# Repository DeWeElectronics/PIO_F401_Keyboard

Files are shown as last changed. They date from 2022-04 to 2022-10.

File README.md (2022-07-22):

# STM32 Mechanical Keyboard

a DIY attempt of a 68 key style mechanical keyboard which not only looks cool, but can also scan at 1000 Hz

click the image below to watch the build video on youtube.

Youtube Video of the build process (http://www.youtube.com/watch?v=smThnvXJ02c)

This keyboard is powered with a STM32F401CC board (a.k.a black pill F401CC)



To build this project, simply clone this project and build it in vscode with PlatformIO IDE

Note : Before building and flashing to the microcontroller, make sure that the keyboard wiring matches this schematic



or instead change the matrix pin definitions in src/main.c (rowPins and colPins) to fit your wiring while paying attention to the key mapping in src/keymap.c

"secret" features:
  - AutoType mode: The keyboard will turn into an automatic text typer configured to output a specific text defined in src/text.c. Each key press will send a character of the text, and a long press will send the characters continuously. Enable autotype mode by pressing and holding FN and all five right-most keys.  
  - AutoPress mode: The keyboard will repeatedly press and unpress the enabled key(s). Enable autopress mode by defining ENABLE_AUTOTYPER in src/main.c (definition has been commented out). Flash the new firmware. Then, on the keyboard, press FN, and the key desired (a key without an alternate mode to avoid conflict with alternate key). Then a long press will repeatedly send the desired key. Disable it by again pressing FN and the desired key, or to disable it for the entire keyboard, press FN and ESC

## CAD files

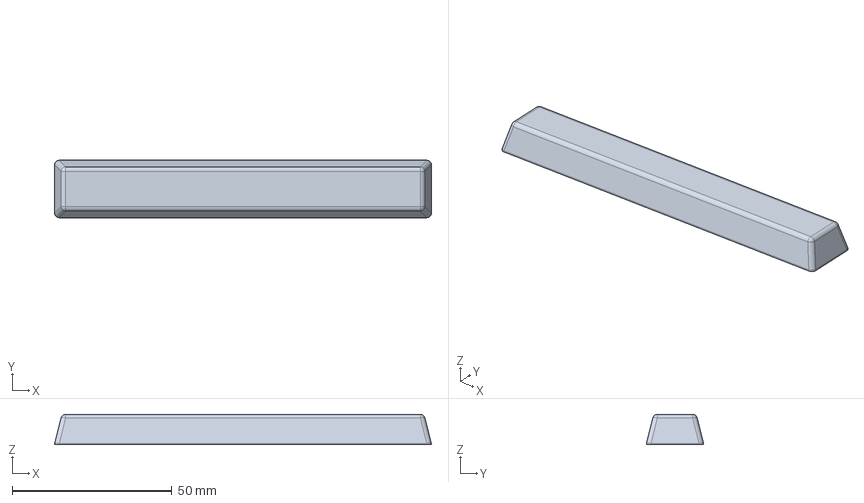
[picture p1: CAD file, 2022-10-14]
STL_Files/FreeCAD files/keycaps uniform 6_25u.FCStd
118.0 x 18.0 x 9.50 mm

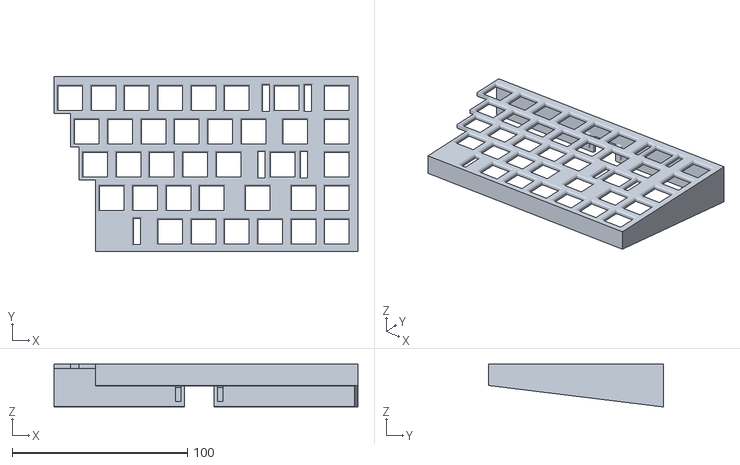
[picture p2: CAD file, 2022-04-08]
STL_Files/KTR_1.stl
173.2 x 100.0 x 24.5

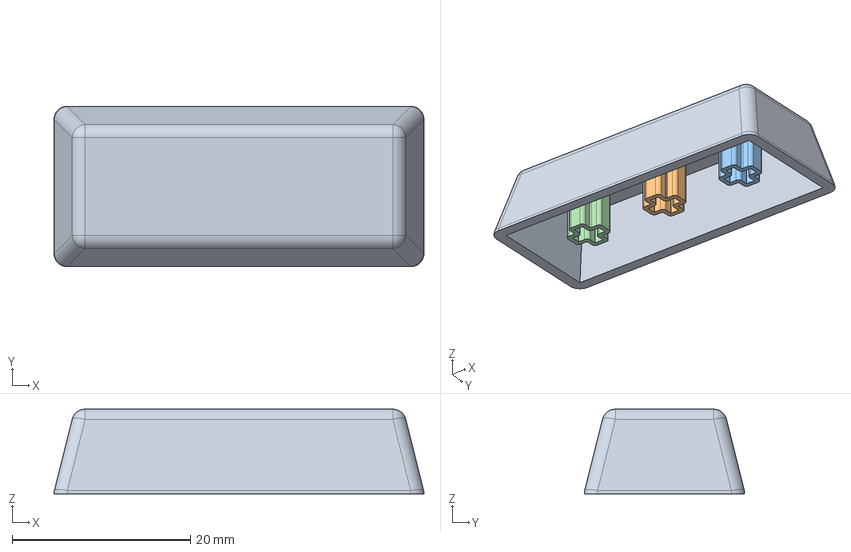
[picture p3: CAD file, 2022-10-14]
STL_Files/FreeCAD files/keycaps uniform 2.25u.FCStd
41.5 x 18.0 x 9.50 mm

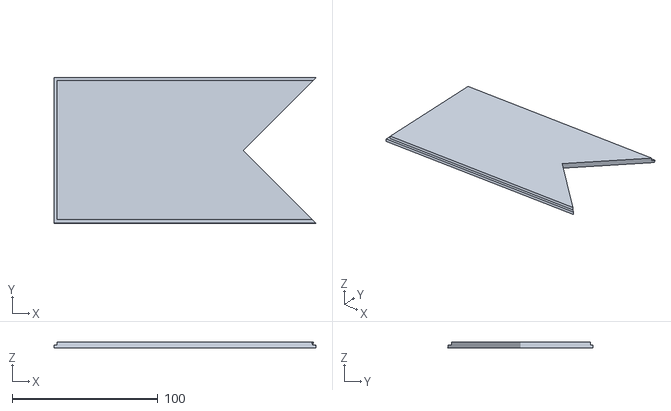
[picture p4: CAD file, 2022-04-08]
STL_Files/KBL_1.stl
180.0 x 100.0 x 4.00

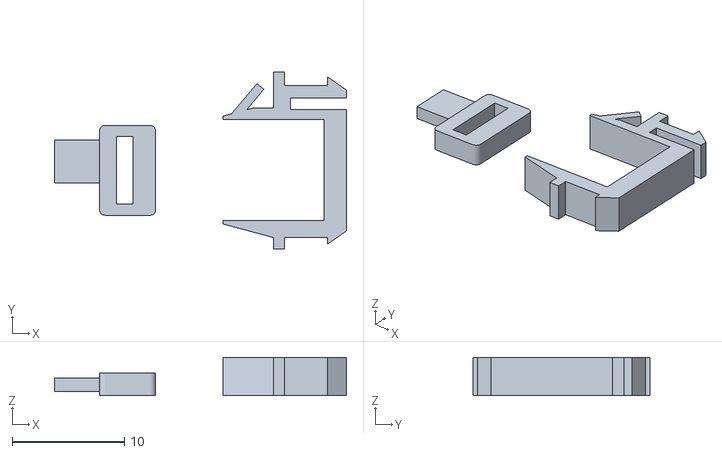
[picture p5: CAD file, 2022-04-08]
STL_Files/costar-stab.stl
26.0 x 15.7 x 3.40

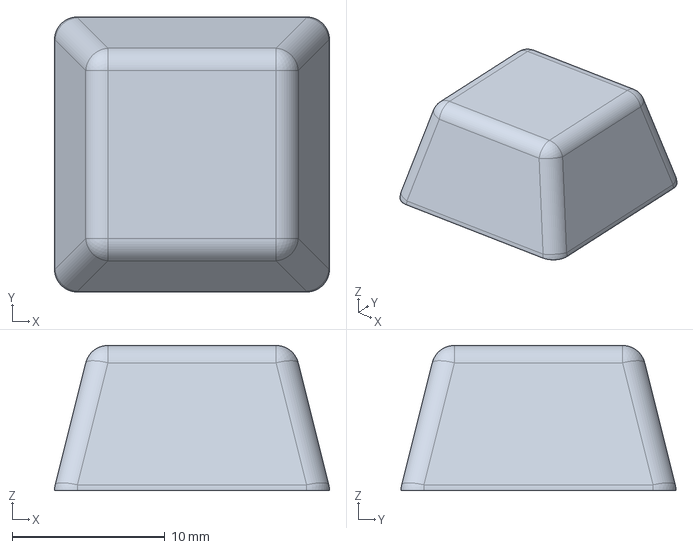
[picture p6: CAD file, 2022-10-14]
STL_Files/FreeCAD files/keycaps uniform.FCStd
18.0 x 18.0 x 9.50 mm

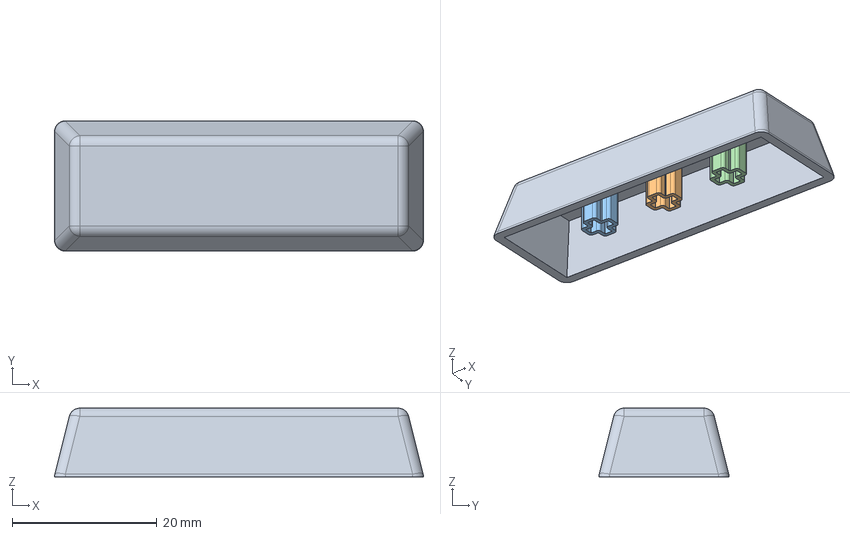
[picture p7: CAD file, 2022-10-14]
STL_Files/FreeCAD files/keycaps uniform 2.75u.FCStd
51.0 x 18.0 x 9.50 mm

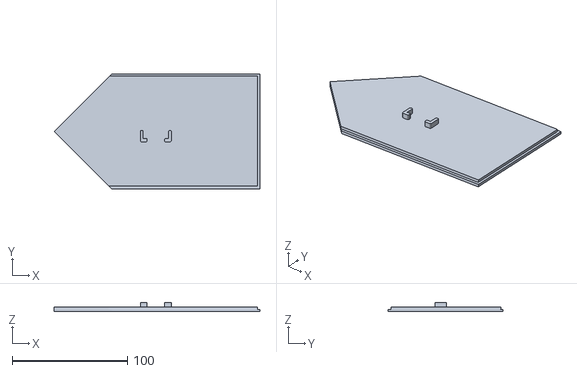
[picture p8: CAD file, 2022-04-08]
STL_Files/KBR_1.stl
179.0 x 100.0 x 8.00

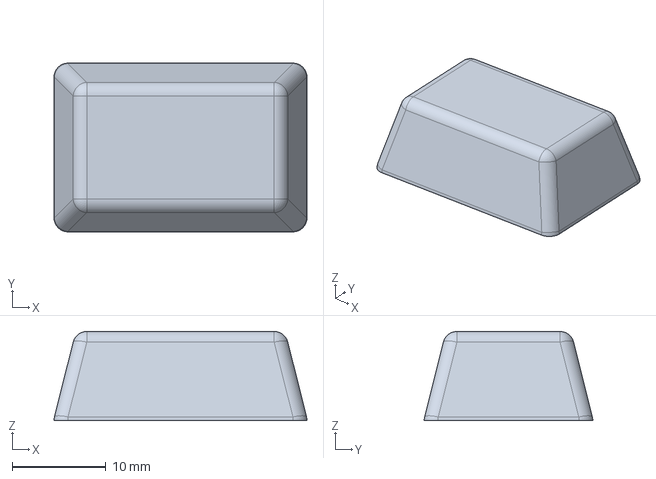
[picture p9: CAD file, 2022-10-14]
STL_Files/FreeCAD files/keycaps uniform 1_5u.FCStd
27.0 x 18.0 x 9.50 mm

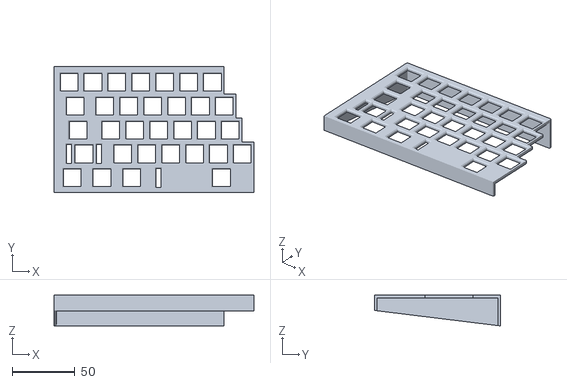
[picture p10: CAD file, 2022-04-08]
STL_Files/KTL_1.stl
159.0 x 100.0 x 24.5

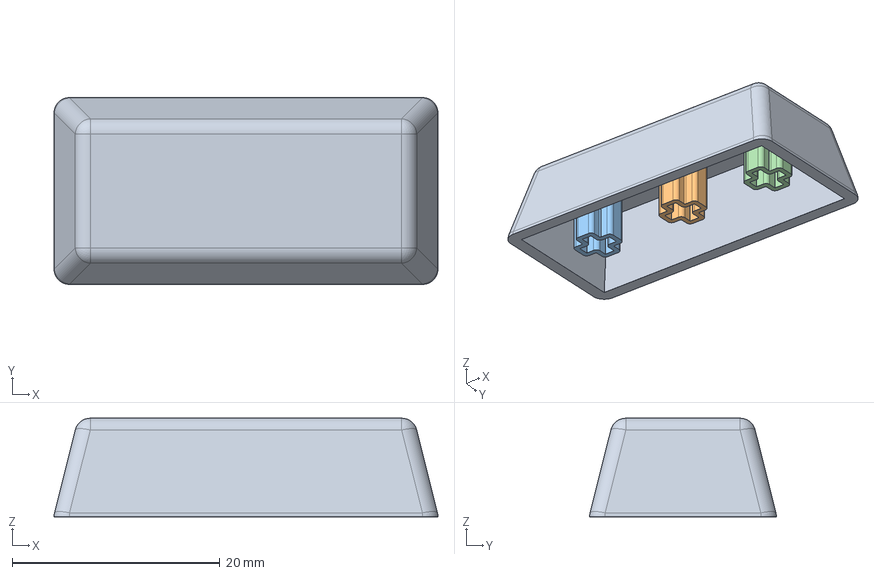
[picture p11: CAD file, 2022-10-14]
STL_Files/FreeCAD files/keycaps uniform 2u.FCStd
37.0 x 18.0 x 9.50 mm

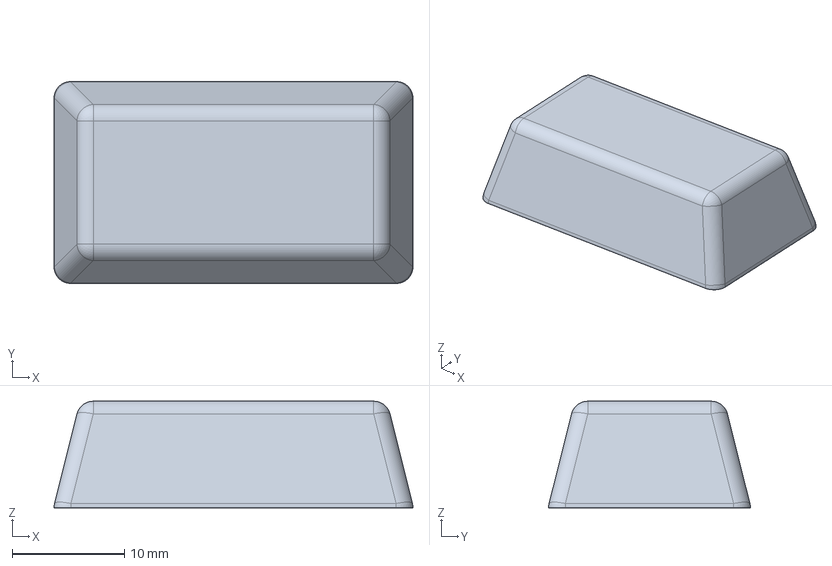
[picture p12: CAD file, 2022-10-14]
STL_Files/FreeCAD files/keycaps uniform 1_75u.FCStd
32.0 x 18.0 x 9.50 mm

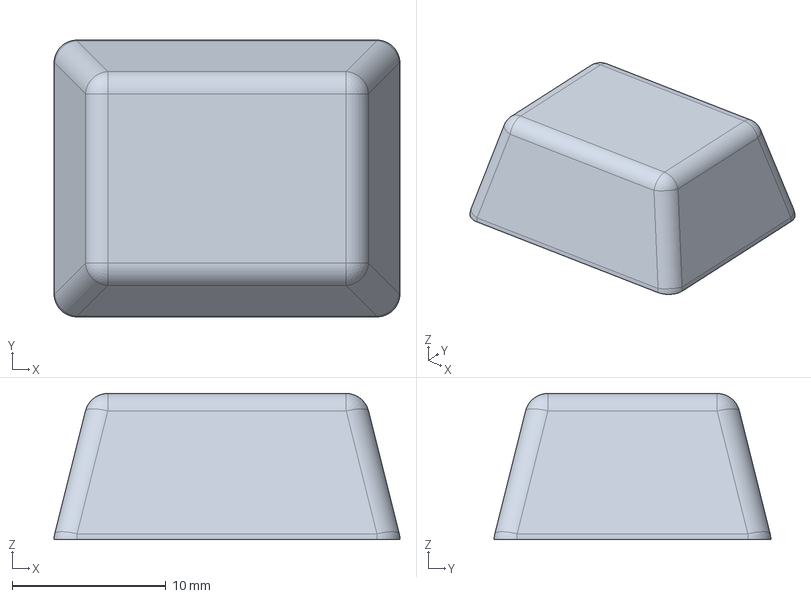
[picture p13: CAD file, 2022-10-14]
STL_Files/FreeCAD files/keycaps uniform 1_25u.FCStd
22.5 x 18.0 x 9.50 mm

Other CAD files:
STL_Files/FreeCAD files/costar_stabs.FCStd
STL_Files/FreeCAD files/keyboard_frame.FCStd
STL_Files/keycaps uniform 1_25u.stl
STL_Files/keycaps uniform 1_5u.stl
STL_Files/keycaps uniform 1_75u.stl
STL_Files/keycaps uniform 2.25u.stl
STL_Files/keycaps uniform 2.75u.stl
STL_Files/keycaps uniform 2u.stl
STL_Files/keycaps uniform 6_25u.stl
STL_Files/keycaps uniform.stl

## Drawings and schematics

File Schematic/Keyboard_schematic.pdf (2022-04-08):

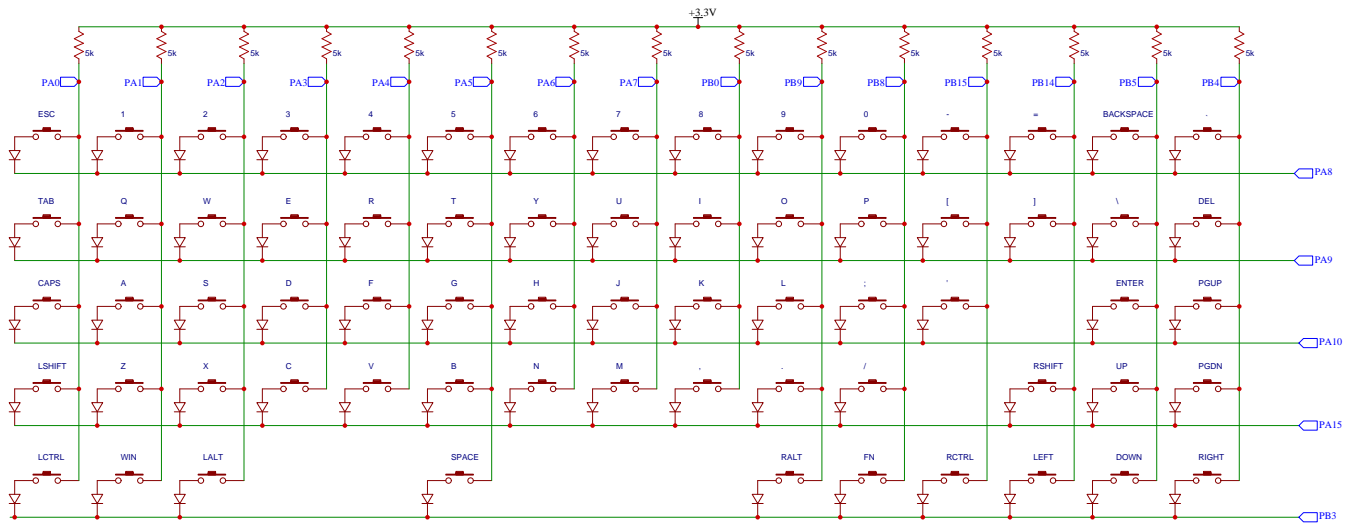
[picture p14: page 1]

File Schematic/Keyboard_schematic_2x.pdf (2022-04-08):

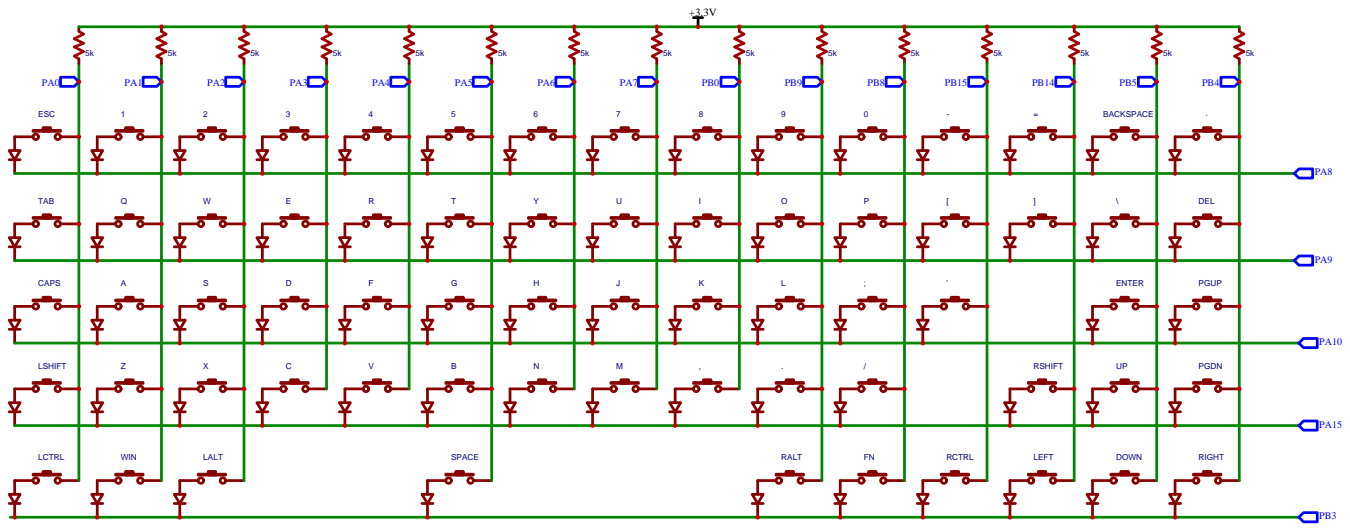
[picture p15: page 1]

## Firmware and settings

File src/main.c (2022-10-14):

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
/* Includes ------------------------------------------------------------------*/
#include "main.h"
#include "usb_device.h"

/* USER CODE BEGIN Includes */
#include "GPIO_Config.h"
#include "keyboard_usb.h"
#include "keymap.h"
#include "stdlib.h"
#include "string.h"
#include "text.h"
/* USER CODE END Includes */

TIM_HandleTypeDef htim3;

void SystemClock_Config(void);
static void MX_GPIO_Init(void);
static void MX_TIM3_Init(void);
/* USER CODE BEGIN 0 */

#define TIMEOUT_MS 100
#define TIMEOUT_MAX 500

extern USBD_HandleTypeDef hUsbDeviceFS;

// #define ENABLE_AUTOTYPER

#define USBD_Keyboard_State() (((volatile USBD_HID_HandleTypeDef*)hUsbDeviceFS.pClassData)->state)

#define COLS 15U
#define ROWS 5U

PinId_t* colPins[COLS] = {
    PA0, PA1, PA2, PA3, PA4,
    PA5, PA6, PA7, PB0, PB9,
    PB8, PB15, PB14, PB5, PB4};

PinId_t* rowPins[ROWS] = {
    PA8,
    PA9,
    PA10,
    PA15,
    PB3,
};

#define HID_NORMAL_ID 1U
#define HID_MEDIA_ID 2U
#define FN_KEY 70U

void keyboard_init(PinId_t** p_rows, PinId_t** p_cols, uint16_t n_rows, uint16_t n_cols) {
    
    __HAL_RCC_GPIOA_CLK_ENABLE();
    __HAL_RCC_GPIOB_CLK_ENABLE();
    __HAL_RCC_GPIOC_CLK_ENABLE();

    for (uint16_t i = 0; i < n_cols; i++) {
        GPIO_InitTypeDef tmp = {0};
        tmp.Pin = p_cols[i]->pinmask;
        tmp.Mode = GPIO_MODE_INPUT;
        tmp.Pull = GPIO_PULLUP;
        tmp.Alternate = 0U;
        HAL_GPIO_Init(p_cols[i]->GPIOx, &tmp);
    }

    for (uint16_t i = 0; i < n_rows; i++) {
        PinId_Write(p_rows[i], 1);
        GPIO_InitTypeDef tmp = {0};
        tmp.Pin = p_rows[i]->pinmask;
        tmp.Mode = GPIO_MODE_OUTPUT_PP;
        tmp.Pull = GPIO_NOPULL;
        tmp.Speed = GPIO_SPEED_FREQ_VERY_HIGH;
        tmp.Alternate = 0U;
        HAL_GPIO_Init(p_rows[i]->GPIOx, &tmp);
    }
}

void keyboard_transmit(uint8_t* data, size_t size) {
    while (USBD_Keyboard_State() != HID_IDLE)
        ;
    USBD_HID_SendReport(&hUsbDeviceFS, data, size);
}

KeyboardHID_t myHID = {HID_NORMAL_ID};
MediaHID_t myMedia = {HID_MEDIA_ID};
uint8_t Pressed[ROWS * COLS] = {0};
uint32_t keyTimer[ROWS * COLS] = {0};
#define ENABLE_AUTOTYPER
#ifdef ENABLE_AUTOTYPER
uint8_t autoPress[ROWS * COLS] = {0};
#endif //ENABLE_AUTOTYPER

void keyboardService() {
    static uint32_t update = 0;
    static uint32_t alternate = 0;
    static uint32_t autotype = 0;
    static uint32_t clean = 0;
    static uint8_t autotypeActivate = 0;
    static uint32_t textPos = 0;
    static uint32_t npressed = 0;

    // scan matrix
    for (uint32_t i = 0; i < ROWS; i++) {
        PinId_Write(rowPins[i], 0);
        volatile uint32_t j = 0;
        for (; j < 10; j++)
            ;
        for (j = 0; j < COLS; j++) {
            uint32_t pos = i * COLS + j;
            uint32_t col_pressed = !PinId_Read(colPins[j]);
            uint32_t thisTick = HAL_GetTick();

            // set/unset alternate mode
            if (pos == FN_KEY) {
                alternate = col_pressed;
                continue;
            }

            if (col_pressed) {
                // autotype mode toggle on press (press and release alt key and column 14 of each row simultaneously)
                if (j == 14) {
                    autotypeActivate |= (1U << i);
                    if ((autotypeActivate == 0x1f) && (alternate == 1)) {
                        if (autotype == 0U) autotype = 2U;
                        else if (autotype == 3U) autotype = 1U;
                    }
                }

                // if alternate mode is on and alternate key is defined
                uint8_t key = (alternate && keys_alternate[pos][0] != 0) ? 
                                (uint8_t)keys_alternate[pos][0] : (uint8_t)keys[pos][0];

#ifdef ENABLE_AUTOTYPER
                if(keys_alternate[pos][0] == 0 && alternate) {
                    switch(autoPress[pos]) {
                        case 0: autoPress[pos] = 2; break;
                        case 3: autoPress[pos] = 1; break;
                        default: break;
                    }
                }
#endif // ENABLE_AUTOTYPER

                // press key
                // if key of 'pos' is free and not in debounce timeout
                // if (Pressed[pos] == 0 && TimeOut[pos] == 0) {
                if (Pressed[pos] == 0 && (thisTick - keyTimer[pos] >= TIMEOUT_MS)) {
                    uint32_t keycode = 0UL;
                    if ((keycode = USBD_Keyboard_str_press(&myHID, &myMedia, key))) {
                        update |= ((keycode & KEY_TYPE_MASK) == KEY_TYPE_MEDIA) ? 8U : 4U; // update HID Type
                        update |= 1U;                                                  // update pressed flag
                        Pressed[pos] = key;                                            // assign key to pressed array
                        npressed++;
                    }
                }
#ifdef ENABLE_AUTOTYPER
                if ((autoPress[pos] == 3) && (Pressed[pos] != 0) && (thisTick - keyTimer[pos] >= TIMEOUT_MAX)) {
                    uint32_t keycode = 0UL;
                    if ((keycode = USBD_Keyboard_str_release(&myHID, &myMedia, Pressed[pos]))) {
                        // update HID Type
                        update |= ((keycode & KEY_TYPE_MASK) == KEY_TYPE_MEDIA) ? 8U : 4U;
                        update |= 2U;              // update release flag
                        Pressed[pos] = 0;          // unassign key from pressed array
                        // TimeOut[pos] = TIMEOUT_MS; // set debounce timeout
                        npressed--;
                    }
                    keyTimer[pos] = thisTick - TIMEOUT_MAX + 50;
                }
#endif // ENABLE_AUTOTYPER
            } 
            if(!col_pressed) {
                // autotype mode toggle on release (press and release alt key and column 14 of each row simultaneously)
                if (j == 14) {
                    autotypeActivate &= ~(1U << i);
                    if (autotypeActivate == 0) {
                        int prevautotype = autotype;
                        if (autotype == 2U) autotype = 3U;
                        else if (autotype == 1U) autotype = 0U;
                        if (prevautotype != autotype) 
                            { clean = 1; textPos = 0; }
                    }
                }

#ifdef ENABLE_AUTOTYPER
                switch(autoPress[pos]) {
                    case 2: autoPress[pos] = 3; break;
                    case 1: autoPress[pos] = 0; break;
                    default: break;
                }
#endif // ENABLE_AUTOTYPER
                
                // release key
                if (Pressed[pos] != 0) { // if key[pos] is pressed
                    uint32_t keycode = 0UL;
                    if ((keycode = USBD_Keyboard_str_release(&myHID, &myMedia, Pressed[pos]))) {
                        // update HID Type
                        update |= ((keycode & KEY_TYPE_MASK) == KEY_TYPE_MEDIA) ? 8U : 4U;
                        update |= 2U;              // update release flag
                        Pressed[pos] = 0;          // unassign key from pressed array
                        npressed--;
                    }
                    keyTimer[pos] = thisTick;
                }
                // keep the max difference of keyTimer and thisTick at TIMEOUT_MS (to avoid overflow)
                keyTimer[pos] = (thisTick - keyTimer[pos] > TIMEOUT_MS)? 
                                    (thisTick - TIMEOUT_MS) : keyTimer[pos];
            }
            keyTimer[pos] = (thisTick - keyTimer[pos] > TIMEOUT_MAX)? 
                                (thisTick - TIMEOUT_MAX) : keyTimer[pos];
        }
        PinId_Write(rowPins[i], 1);
    }

#ifdef ENABLE_AUTOTYPER
    if (autoPress[0] == 3)
        clean = 1;
#endif // ENABLE_AUTOTYPER
    
    static uint32_t autotypeTimer = 0;
    if (autotype == 3) {    // autotype long press
        if ((HAL_GetTick() - autotypeTimer >= 500) && npressed > 0) {
            update |= 1U;
            autotypeTimer = HAL_GetTick() - (500);
        } else if (npressed == 0) {
            autotypeTimer = HAL_GetTick();
            textPos %= size_txt;
        }
    }

    // send report
    if (update & 3U) {
        if (clean) { // clean output
#ifdef ENABLE_AUTOTYPER
            memset(autoPress, 0, sizeof(autoPress));
#endif // ENABLE_AUTOTYPER
            uint8_t tmp[9] = {HID_NORMAL_ID, 0, 0, 0, 0, 0, 0, 0, 0};
            uint8_t tmp1[3] = {HID_MEDIA_ID, 0, 0};
            keyboard_transmit((uint8_t*)tmp, 9);
            keyboard_transmit((uint8_t*)tmp1, 3);
            clean = 0;
        }
        if (((update & 1U) == 1U) && autotype == 3) { // autotype mode
            // new HID instance
            KeyboardHID_t autotypeHID = {HID_NORMAL_ID, 0, 0, {0, 0, 0, 0, 0, 0}};
            MediaHID_t autotypeMedia = {HID_MEDIA_ID, {0, 0}};
            // press
            if (textPos < size_txt) {
                uint32_t type = USBD_Keyboard_str_press(&autotypeHID, &autotypeMedia, txt[textPos++]);
                type = (type & KEY_TYPE_MASK) == KEY_TYPE_MEDIA;
                if (type) {
                    keyboard_transmit((uint8_t*)&autotypeMedia, sizeof(autotypeMedia));
                    // release
                    USBD_Keyboard_releaseAll(&autotypeHID, &autotypeMedia);
                    keyboard_transmit((uint8_t*)&autotypeMedia, sizeof(autotypeMedia));
                } else {
                    keyboard_transmit((uint8_t*)&autotypeHID, sizeof(autotypeHID));
                    // release
                    USBD_Keyboard_releaseAll(&autotypeHID, &autotypeMedia);
                    keyboard_transmit((uint8_t*)&autotypeHID, sizeof(autotypeHID));
                }
            }
        } else if (autotype == 0) { // normal mode
            if (update & 8U) {
                myMedia.ID = HID_MEDIA_ID;
                keyboard_transmit((uint8_t*)&myMedia, sizeof(myMedia));
            }
            if (update & 4U) {
                myHID.ID = HID_NORMAL_ID;
                keyboard_transmit((uint8_t*)&myHID, sizeof(myHID));
            }
        }
        update = 0;
    }
}

volatile uint32_t LED_toggle = 0U;

void USBD_HID_GetReport(uint8_t* OutData, int len) {
    if (OutData[0] == 0x01) {
        PinId_Write(PC14, OutData[1] & 1U);
        PinId_Write(PC15, OutData[1] & 2U);
    }
}

void __attribute__((optimize("-O0"))) HAL_TIM_PeriodElapsedCallback(TIM_HandleTypeDef* htim) {

    if (htim == &htim3) {
        PinId_Write(PC13, !(!(USBD_Keyboard_State() == HID_IDLE) || PinId_Read(PC13)));
        // PinId_Write(PC13, !((USBD_Keyboard_State() == HID_IDLE) && PinId_Read(PC13)));
        // if (USBD_Keyboard_State() == HID_IDLE)
        //     PinId_Toggle(PC13);
    }
    // NVIC_DisableIRQ(TIM3_IRQn);
    // keyboardService();
    // NVIC_EnableIRQ(TIM3_IRQn);
}

/* USER CODE END 0 */

/**
 * @brief  The application entry point.
 * @retval int
 */
int __attribute__((optimize("-O0"))) main(void) {
    /* MCU Configuration--------------------------------------------------------*/

    /* Reset of all peripherals, Initializes the Flash interface and the Systick. */
    HAL_Init();

    /* Configure the system clock */
    SystemClock_Config();

    /* USER CODE BEGIN SysInit */

    NVIC_SetPriority(OTG_FS_IRQn, 6);
    NVIC_SetPriority(TIM3_IRQn, 67);
    /* USER CODE END SysInit */

    /* Initialize all configured peripherals */
    MX_GPIO_Init();
    MX_TIM3_Init();
    HAL_Delay(50);
    MX_USB_DEVICE_Init();
    HAL_Delay(50);
    /* USER CODE BEGIN 2 */
    keyboard_init(rowPins, colPins, ROWS, COLS);
    TIM3->PSC = (84000000 / 10000) - 1;
    TIM3->ARR = (10000 / 1) - 1;
    // NVIC_SetPriority(OTG_FS_IRQn, 6);
    // NVIC_SetPriority(TIM3_IRQn, 67);
    HAL_TIM_Base_Start_IT(&htim3);

    while (USBD_Keyboard_State() != HID_IDLE)
        ;
    LED_toggle = 1U;

    /* USER CODE END 2 */

    /* Infinite loop */
    /* USER CODE BEGIN WHILE */
    while (1) {
        /* USER CODE END WHILE */

        /* USER CODE BEGIN 3 */
        static uint32_t lastScan = 0UL;
        if (lastScan != HAL_GetTick()) {
            lastScan = HAL_GetTick();
            keyboardService();
        }
    }
    /* USER CODE END 3 */
}

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


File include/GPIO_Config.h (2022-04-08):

/*!
 * @file GPIO_Config.h
 * @author Demitrias Wilbert 
 * @brief definition to pointer to each pin configuration structure type (PinId_t)
 * @version 0.1
 * @date 2021-07-08
 * 
 * 
*/

#ifndef GPIO_CONFIG_H
#define GPIO_CONFIG_H

#include "main.h"

/*!
 * @struct PinId_t
 * @brief pin configuration structure typedef
 * 
 * @var PinId_t::GPIO_TypeDef 
 *  pointer to the pin GPIO Base
 * @var PinId_t::pinmask
 *  bitmask of the pin
 * @var PinId_t::pin
 *  index of the pin
 * 
*/
typedef struct
{
    GPIO_TypeDef* GPIOx;
    uint16_t pinmask;
    uint16_t pin;
} PinId_t;


/*!
 * @brief 
 * undef the unnecessary GPIOs to save memory
 * e.g: STM32F103C8T6 only has GPIOA, GPIOB, GPIOC, GPIOD
 * so undef the rest
 *
*/


#ifdef GPIOA
extern const PinId_t PIN_PA0;
#define PA0 ((PinId_t*) &PIN_PA0)
extern const PinId_t PIN_PA1;
#define PA1 ((PinId_t*) &PIN_PA1)
extern const PinId_t PIN_PA2;
#define PA2 ((PinId_t*) &PIN_PA2)
extern const PinId_t PIN_PA3;
#define PA3 ((PinId_t*) &PIN_PA3)
extern const PinId_t PIN_PA4;
#define PA4 ((PinId_t*) &PIN_PA4)
extern const PinId_t PIN_PA5;
#define PA5 ((PinId_t*) &PIN_PA5)
extern const PinId_t PIN_PA6;
#define PA6 ((PinId_t*) &PIN_PA6)
extern const PinId_t PIN_PA7;
#define PA7 ((PinId_t*) &PIN_PA7)
extern const PinId_t PIN_PA8;
#define PA8 ((PinId_t*) &PIN_PA8)
extern const PinId_t PIN_PA9;
#define PA9 ((PinId_t*) &PIN_PA9)
extern const PinId_t PIN_PA10;
#define PA10 ((PinId_t*) &PIN_PA10)
extern const PinId_t PIN_PA11;
#define PA11 ((PinId_t*) &PIN_PA11)
extern const PinId_t PIN_PA12;
#define PA12 ((PinId_t*) &PIN_PA12)
extern const PinId_t PIN_PA13;
#define PA13 ((PinId_t*) &PIN_PA13)
extern const PinId_t PIN_PA14;
#define PA14 ((PinId_t*) &PIN_PA14)
extern const PinId_t PIN_PA15;
#define PA15 ((PinId_t*) &PIN_PA15)
#endif // GPIOA

#ifdef GPIOB
extern const PinId_t PIN_PB0;
#define PB0 ((PinId_t*) &PIN_PB0)
extern const PinId_t PIN_PB1;
#define PB1 ((PinId_t*) &PIN_PB1)
extern const PinId_t PIN_PB2;
#define PB2 ((PinId_t*) &PIN_PB2)
extern const PinId_t PIN_PB3;
#define PB3 ((PinId_t*) &PIN_PB3)
extern const PinId_t PIN_PB4;
#define PB4 ((PinId_t*) &PIN_PB4)
extern const PinId_t PIN_PB5;
#define PB5 ((PinId_t*) &PIN_PB5)
extern const PinId_t PIN_PB6;
#define PB6 ((PinId_t*) &PIN_PB6)
extern const PinId_t PIN_PB7;
#define PB7 ((PinId_t*) &PIN_PB7)
extern const PinId_t PIN_PB8;
#define PB8 ((PinId_t*) &PIN_PB8)
extern const PinId_t PIN_PB9;
#define PB9 ((PinId_t*) &PIN_PB9)
extern const PinId_t PIN_PB10;
#define PB10 ((PinId_t*) &PIN_PB10)
extern const PinId_t PIN_PB11;
#define PB11 ((PinId_t*) &PIN_PB11)
extern const PinId_t PIN_PB12;
#define PB12 ((PinId_t*) &PIN_PB12)
extern const PinId_t PIN_PB13;
#define PB13 ((PinId_t*) &PIN_PB13)
extern const PinId_t PIN_PB14;
#define PB14 ((PinId_t*) &PIN_PB14)
extern const PinId_t PIN_PB15;
#define PB15 ((PinId_t*) &PIN_PB15)
#endif // GPIOB

#ifdef GPIOC
extern const PinId_t PIN_PC0;
#define PC0 ((PinId_t*) &PIN_PC0)
extern const PinId_t PIN_PC1;
#define PC1 ((PinId_t*) &PIN_PC1)
extern const PinId_t PIN_PC2;
#define PC2 ((PinId_t*) &PIN_PC2)
extern const PinId_t PIN_PC3;
#define PC3 ((PinId_t*) &PIN_PC3)
extern const PinId_t PIN_PC4;
#define PC4 ((PinId_t*) &PIN_PC4)
extern const PinId_t PIN_PC5;
#define PC5 ((PinId_t*) &PIN_PC5)
extern const PinId_t PIN_PC6;
#define PC6 ((PinId_t*) &PIN_PC6)
extern const PinId_t PIN_PC7;
#define PC7 ((PinId_t*) &PIN_PC7)
extern const PinId_t PIN_PC8;
#define PC8 ((PinId_t*) &PIN_PC8)
extern const PinId_t PIN_PC9;
#define PC9 ((PinId_t*) &PIN_PC9)
extern const PinId_t PIN_PC10;
#define PC10 ((PinId_t*) &PIN_PC10)
extern const PinId_t PIN_PC11;
#define PC11 ((PinId_t*) &PIN_PC11)
extern const PinId_t PIN_PC12;
#define PC12 ((PinId_t*) &PIN_PC12)
extern const PinId_t PIN_PC13;
#define PC13 ((PinId_t*) &PIN_PC13)
extern const PinId_t PIN_PC14;
#define PC14 ((PinId_t*) &PIN_PC14)
extern const PinId_t PIN_PC15;
#define PC15 ((PinId_t*) &PIN_PC15)
#endif // GPIOC
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

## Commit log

2022-06-25 add disable all autotype feature disable all autotype keys with (fn + esc) meaning that the autotype feature cannot be used on ESC key
2022-07-18 chagne EPIN size to 16 bytes Keyboard can now report at 1000 Hz
2022-07-22 fix autopress not activating
    [main.c]
2022-07-24 fix autopress not enabling
    [main.c]
2022-10-14 change keycap stem design
    [keycaps uniform 1_25u.FCStd, keycaps uniform 1_25u.stl, keycaps uniform 1_5u.FCStd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]

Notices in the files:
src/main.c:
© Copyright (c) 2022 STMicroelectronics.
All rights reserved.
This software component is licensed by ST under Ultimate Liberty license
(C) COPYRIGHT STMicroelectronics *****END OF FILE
